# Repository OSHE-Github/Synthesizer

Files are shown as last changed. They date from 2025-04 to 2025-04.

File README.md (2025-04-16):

# Synthesizer

**Tips for uploading and running firmware on the Teensy**

- You will need the Arduino IDE to upload the firmware to the Teensy. Instructions: [Arduino IDE install instructions](https://support.arduino.cc/hc/en-us/articles/360019833020-Download-and-install-Arduino-IDE)
- Once Arduino IDE is installed, you will need the Teensyduino support package for Arduino IDE. Instructions: [Teensyduino install instructions](https://www.pjrc.com/teensy/td_download.html)
- You will also need to add the MIDI library into Arduino IDE. Instructions: [MIDI library instrall instructions](https://www.pjrc.com/teensy/td_libs_MIDI.html)
- The firmware should then be able to compile in Arduino IDE and upload to the Teensy by clicking the upload button. Make sure the Teensy is selected by going to Tools/Ports/ and select the correct serial port the Teensy is plugged into.

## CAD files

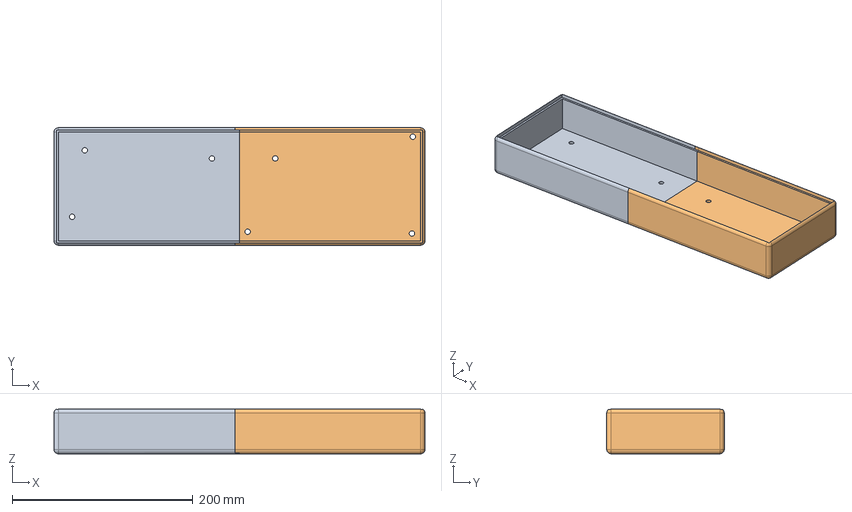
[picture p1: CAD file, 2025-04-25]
newcad/case-bottom-exploded.FCStd
410.0 x 130.0 x 49.3 mm
Slice.0
Slice.1

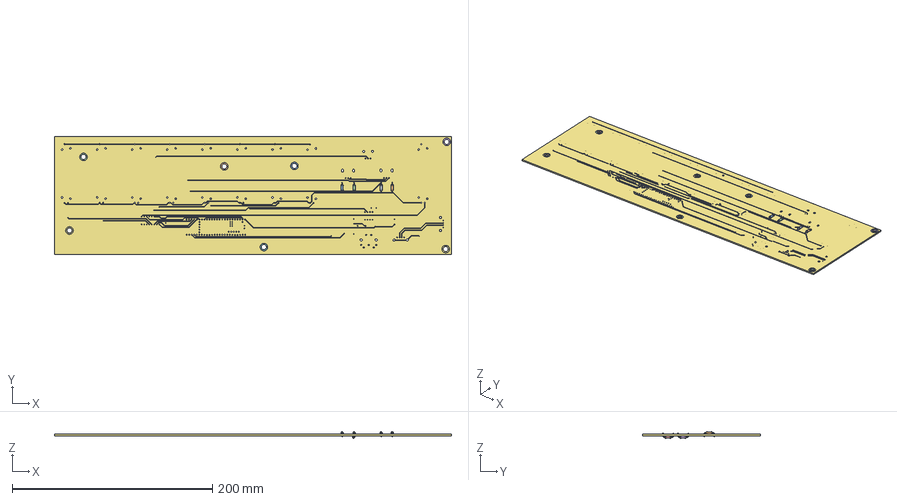
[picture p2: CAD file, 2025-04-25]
newcad/PCB.FCStd
396.2 x 117.5 x 6.66 mm
R_Axial_DIN0207_L6.3mm_D2.5mm_P10.16mm_Horizontal
R_Axial_DIN0207_L6.3mm_D2.5mm_P10.16mm_Horizontal001
R_Axial_DIN0207_L6.3mm_D2.5mm_P10.16mm_Horizontal002
R_Axial_DIN0207_L6.3mm_D2.5mm_P10.16mm_Horizontal003
R_Axial_DIN0207_L6.3mm_D2.5mm_P10.16mm_Horizontal004
R_Axial_DIN0207_L6.3mm_D2.5mm_P10.16mm_Horizontal005
Polysynth edit_copper
Polysynth edit_copper001
Polysynth edit_copper002
Polysynth edit_copper003
Polysynth edit_copper004
Polysynth edit_copper005
Polysynth edit_copper006
Polysynth edit_copper007
Polysynth edit_copper008
Polysynth edit_copper009
Polysynth edit_copper010
Polysynth edit_copper011
Polysynth edit_copper012
Polysynth edit_copper013
Polysynth edit_copper014
Polysynth edit_copper015
Polysynth edit_copper016
Polysynth edit_copper017
Polysynth edit_copper018
Polysynth edit_copper019
Polysynth edit_copper020
Polysynth edit_copper021
Polysynth edit_copper022
Polysynth edit_copper023
Polysynth edit_copper024
Polysynth edit_copper025
Polysynth edit_copper026
Polysynth edit_copper027
Polysynth edit_copper028
Polysynth edit_copper029
Polysynth edit_copper030
Polysynth edit_copper031
Polysynth edit_copper032
Polysynth edit_copper033
Polysynth edit_copper034
Polysynth edit_copper035
Polysynth edit_copper036
Polysynth edit_copper037
Polysynth edit_copper038
Polysynth edit_copper039
Polysynth edit_copper040
Polysynth edit_copper041
Polysynth edit_copper042
Polysynth edit_copper043
Polysynth edit_copper044
Polysynth edit_copper045
Polysynth edit_copper046
Polysynth edit_copper047
Polysynth edit_copper048
Polysynth edit_copper049
Polysynth edit_copper050
Polysynth edit_copper051
Polysynth edit_copper052
Polysynth edit_copper053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

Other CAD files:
newcad/case-bottom.FCStd

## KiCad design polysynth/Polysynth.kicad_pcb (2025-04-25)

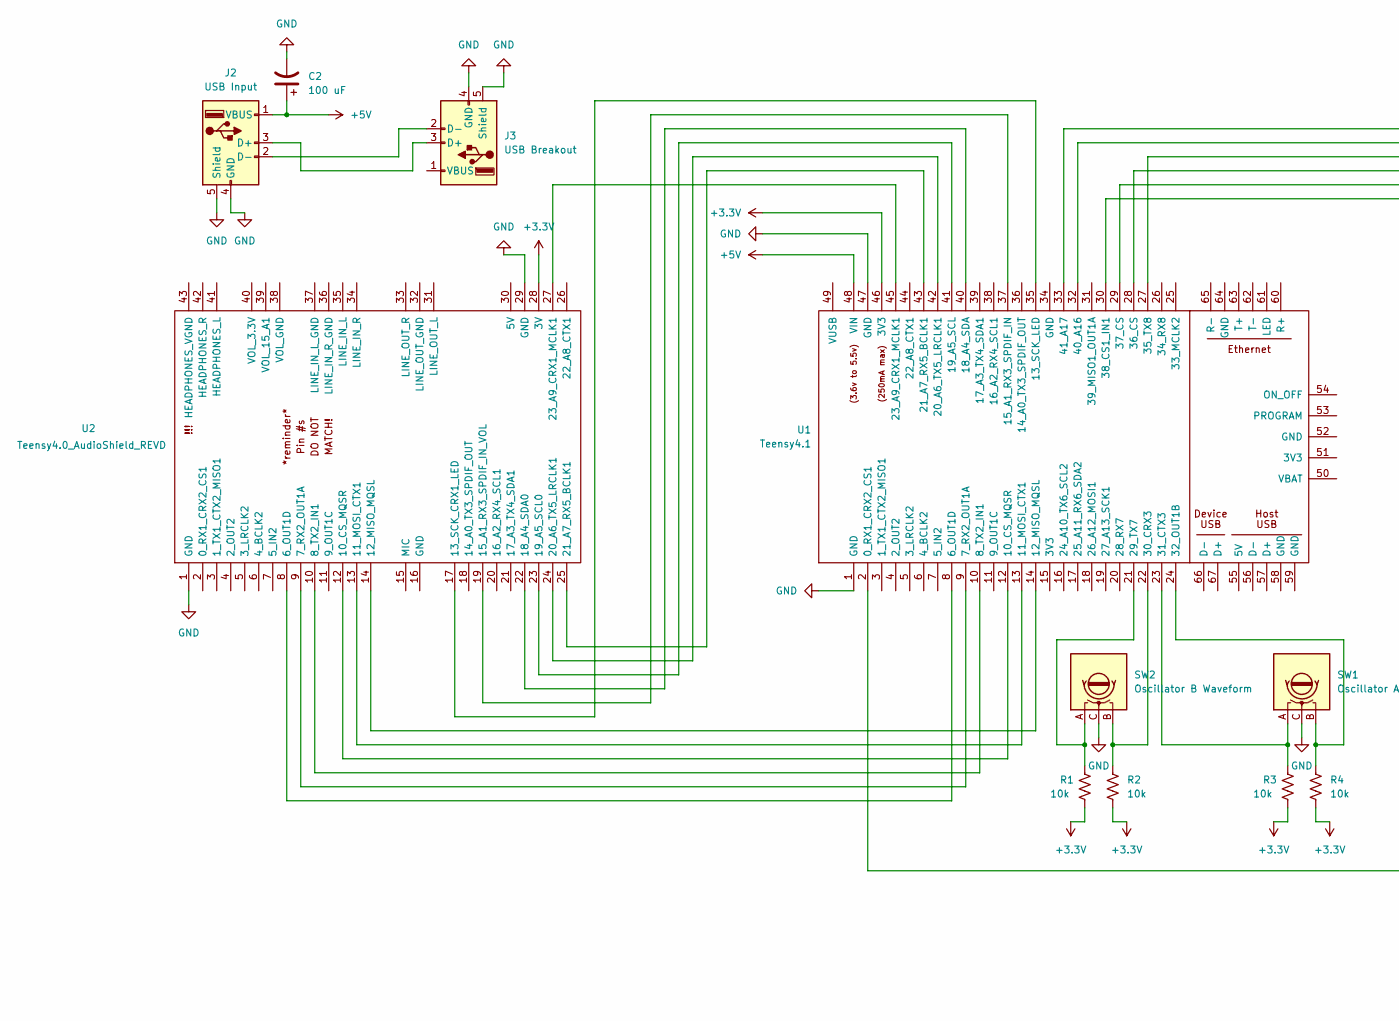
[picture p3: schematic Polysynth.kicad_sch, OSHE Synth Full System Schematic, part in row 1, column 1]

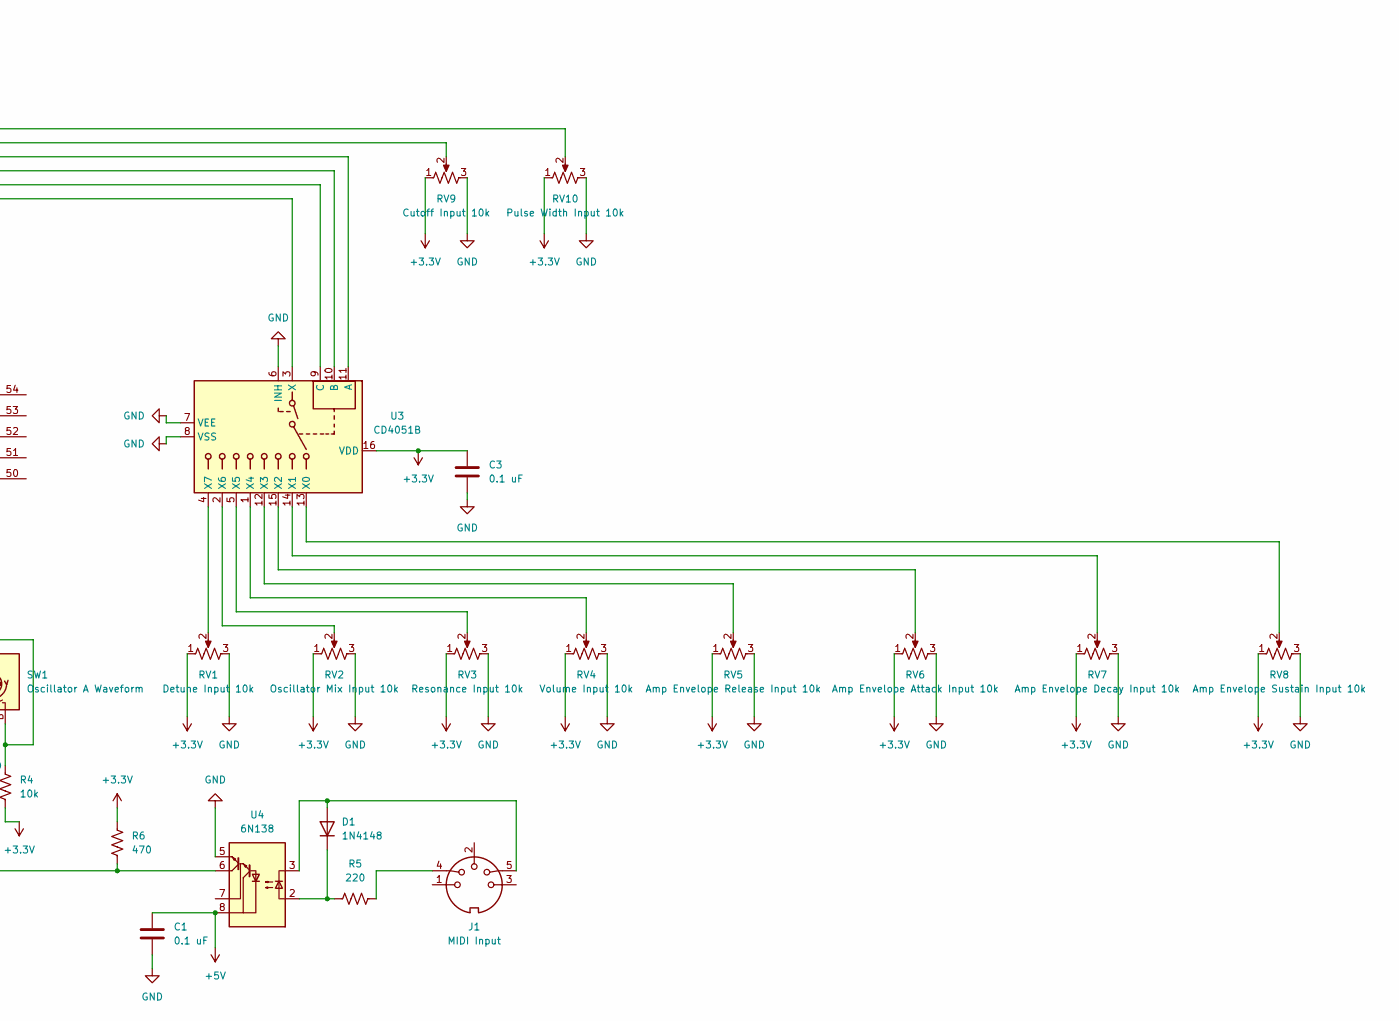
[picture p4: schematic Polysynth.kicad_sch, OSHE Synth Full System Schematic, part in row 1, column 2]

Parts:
C1, C3: 0.1 uF; radial_cap
C2: 100 uF; radial_cap_med
D1: 1N4148; DO-35_02_VIS
J1: MIDI Input; MIDI
J2: USB Input; USB_A_Stewart_SS-52100-001_Horizontal
J3: USB Breakout; USB_A_Stewart_SS-52100-001_Horizontal
R1, R2, R3, R4: 10k; R_Axial_DIN0207_L6.3mm_D2.5mm_P10.16mm_Horizontal
R5: 220; R_Axial_DIN0207_L6.3mm_D2.5mm_P10.16mm_Horizontal
R6: 470; R_Axial_DIN0207_L6.3mm_D2.5mm_P10.16mm_Horizontal
RV1: Detune Input 10k; Potentiometer_Bourns_PTA4543_Single_Slide
RV2: Oscillator Mix Input 10k; PDB12H4301103BF
RV3: Resonance Input 10k; Potentiometer_Bourns_PTA4543_Single_Slide
RV4: Volume Input 10k; Potentiometer_Bourns_PTA4543_Single_Slide
RV5: Amp Envelope Release Input 10k; Potentiometer_Bourns_PTA4543_Single_Slide
RV6: Amp Envelope Attack Input 10k; Potentiometer_Bourns_PTA4543_Single_Slide
RV7: Amp Envelope Decay Input 10k; Potentiometer_Bourns_PTA4543_Single_Slide
RV8: Amp Envelope Sustain Input 10k; Potentiometer_Bourns_PTA4543_Single_Slide
RV9: Cutoff Input 10k; Potentiometer_Bourns_PTA4543_Single_Slide
RV10: Pulse Width Input 10k; Potentiometer_Bourns_PTA4543_Single_Slide
SW1: Oscillator A Waveform; RotaryEncoder_Bourns_Vertical_PEC12R-3x17F-Nxxxx
SW2: Oscillator B Waveform; RotaryEncoder_Bourns_Vertical_PEC12R-3x17F-Nxxxx
U1: Teensy4.1; Teensy41
U2: Teensy4.0_AudioShield_REVD; 4.0audioshield
U3: CD4051B; CD4051BE
U4: 6N138

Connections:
+3.3V: C3.1, R1.2, R2.2, R3.2, R4.2, R6.1, RV1.1, RV2.1, RV3.1, RV4.1, RV5.1, RV6.1, RV7.1, RV8.1, RV9.1, RV10.1, U1.46 (3V3), U2.28 (3V), U3.16 (VDD)
+5V: C1.2, C2.1, J2.1 (VBUS), U1.48 (VIN), U4.8 (VCC)
GND: C1.1, C2.2, C3.2, J2.4 (GND), J2.5 (Shield), J3.4 (GND), J3.5 (Shield), RV1.3, RV2.3, RV3.3, RV4.3, RV5.3, RV6.3, RV7.3, RV8.3, RV9.3, RV10.3, SW1.C, SW2.C, U1.1 (GND), U1.47 (GND), U2.1 (GND), U2.29 (GND), U3.6 (INH), U3.7 (VEE), U3.8 (VSS), U4.5 (GND)
unnamed: D1.2 (A), J1.5, U4.3 (C2)
unnamed: D1.1 (K), R5.1, U4.2 (C1)
unnamed: J1.4, R5.2
unnamed: J2.3 (D+), J3.3 (D+)
unnamed: J2.2 (D-), J3.2 (D-)
unnamed: R6.2, U1.2 (0_RX1_CRX2_CS1), U4.6 (VO2)
unnamed: U1.8 (6_OUT1D), U2.8 (6_OUT1D)
unnamed: U1.9 (7_RX2_OUT1A), U2.9 (7_RX2_OUT1A)
unnamed: U1.10 (8_TX2_IN1), U2.10 (8_TX2_IN1)
unnamed: U1.12 (10_CS_MQSR), U2.12 (10_CS_MQSR)
unnamed: U1.13 (11_MOSI_CTX1), U2.13 (11_MOSI_CTX1)
unnamed: U1.14 (12_MISO_MQSL), U2.14 (12_MISO_MQSL)
unnamed: U1.35 (13_SCK_LED), U2.17 (13_SCK_CRX1_LED)
unnamed: U1.37 (15_A1_RX3_SPDIF_IN), U2.19 (15_A1_RX3_SPDIF_IN_VOL)
unnamed: U1.40 (18_A4_SDA), U2.22 (18_A4_SDA0)
unnamed: U1.41 (19_A5_SCL), U2.23 (19_A5_SCL0)
unnamed: U1.42 (20_A6_TX5_LRCLK1), U2.24 (20_A6_TX5_LRCLK1)
unnamed: U1.43 (21_A7_RX5_BCLK1), U2.25 (21_A7_RX5_BCLK1)
unnamed: U1.45 (23_A9_CRX1_MCLK1), U2.27 (23_A9_CRX1_MCLK1)
unnamed: R1.1, SW2.A, U1.21 (29_TX7)
unnamed: R2.1, SW2.B, U1.22 (30_CRX3)
unnamed: R3.1, SW1.A, U1.23 (31_CTX3)
unnamed: R4.1, SW1.B, U1.24 (32_OUT1B)
unnamed: U1.27 (35_TX8), U3.11 (A)
unnamed: U1.28 (36_CS), U3.10 (B)
unnamed: U1.29 (37_CS), U3.9 (C)
unnamed: U1.30 (38_CS1_IN1), U3.3 (X)
unnamed: RV9.2, U1.32 (40_A16)
unnamed: RV10.2, U1.33 (41_A17)
unnamed: RV8.2, U3.13 (X0)
unnamed: RV7.2, U3.14 (X1)
unnamed: RV6.2, U3.15 (X2)
unnamed: RV5.2, U3.12 (X3)
unnamed: RV4.2, U3.1 (X4)
unnamed: RV3.2, U3.5 (X5)
unnamed: RV2.2, U3.2 (X6)
unnamed: RV1.2, U3.4 (X7)

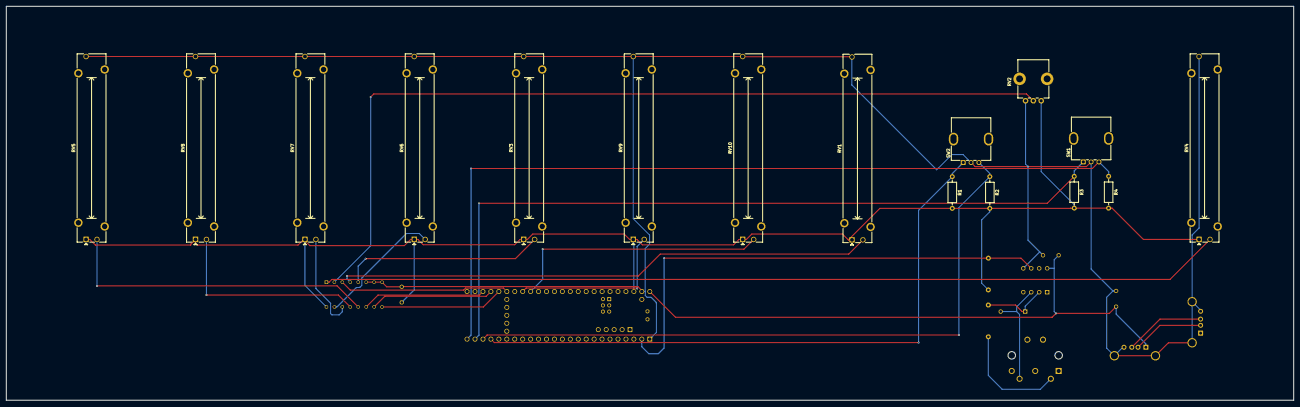
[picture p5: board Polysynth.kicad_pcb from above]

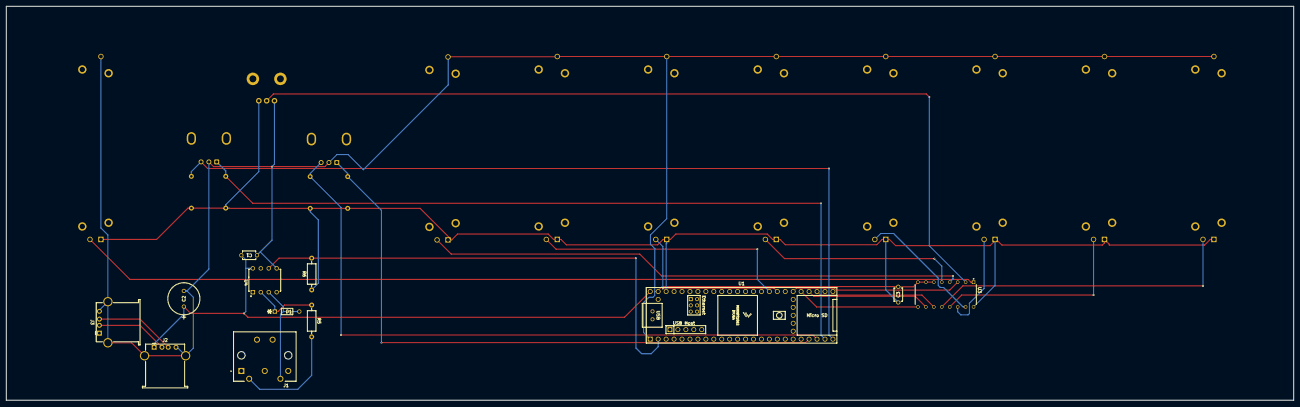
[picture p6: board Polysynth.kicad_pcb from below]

Board: 2 copper layers, 411.7 x 126.0 mm, 28 parts (12 on the bottom side), 27 nets.

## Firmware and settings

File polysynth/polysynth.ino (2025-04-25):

#include <MIDI.h>
#include <Audio.h>
#include <Wire.h>
#include <SPI.h>
#include <SD.h>
#include <SerialFlash.h>

MIDI_CREATE_INSTANCE(HardwareSerial, Serial1, MIDI); // create MIDI instance listening on Serial1 

const int voices = 8; // how many notes can be played at once
const int oscillators = 2; // how many oscillators (waveforms) per voice
const int waveforms = 5; // how many different waveshapes to choose from
const int waveform_switchA1 = 32; // pins of waveform selector switch for oscillators A and B
const int waveform_switchB1 = 30; 
const int waveform_switchA2 = 31;
const int waveform_switchB2 = 29;
const int led_pin = 31; // pin of indicator LED
const int mux1_s0 = 35; // pins used for mux select bits
const int mux1_s1 = 36;
const int mux1_s2 = 37;
const int mux1_inputs = 8; // how many inputs are used on mux 1

bool found_match = false; // utility variable used for searching arrays
byte midi_type = 0; // type of MIDI message being sent
int *midi_stack_ptr; // address of midi stack array
int default_waveform = 0;
int midi_note = 0; // which note was played
int midi_stack_index = 0; // current location in the MIDI stack
int notes_pressed_count = 0; // how many notes are currently held down
int notes_on_count = 0; // how many notes are currently sounding
int analog_res = 1024; // bit resolution used by ADCs
int detune_pot = 0; // _pot are values read from respective pots
int cutoff_pot = 0; 
int resonance_pot = 0; 
int amp_envelope_attack_pot = 0;
int amp_envelope_decay_pot = 0;
int amp_envelope_sustain_pot = 0;
int amp_envelope_release_pot = 0;
int pulse_width_pot = 0;
int volume_pot = 0;
int osc_mix_pot = 0;
int cutoff_range = 14950; // frequency range of filter (Hz)
int envelope_time_range = 11880; // time range of envelope parameters (ms)
int release_queue_count = 0; // amount of voices currently releasing
int waveform_switch_stateA = 0; // current status of the encoder (being turned or not)
int prev_waveform_switch_stateA = 1; // previous status of the encoder
int waveform_switch_stateB = 0;
int prev_waveform_switch_stateB = 1;
int new_voice = 0; // voice chosen to be used by allocation logic
float max_voice_gain = 0.12; // maximum allowed gain of a single voice (1/8 because 8 voices)
float filter_cutoff = 0; // current filter cutoff (Hz)
float filter_resonance = 0; // current filter resonance gain
float osc2_detune = 0; // current oscillator 2 detune (percent)
float pulse_width = 0; // current pulse width of pulse waveform (percent / 100)
float amp_envelope_decay = 0; // current amp envelope decay time (ms)
float amp_envelope_attack = 0; // current amp envelope attack time (ms)
float amp_envelope_release = 0; // currnet amp envelope release time (ms)
float pulse_width_range = 0.47; // range of pulse waveform pulse width (percent / 100)
float pulse_width_inc = 0; // _inc are scalar multipliers for interpreting pot values
float output_volume = 0; // gain of output volume (0-1)
float envelope_time_inc = 0;
float amp_sustain_level = 0; // envelope sustain level (0-1)
float cutoff_inc = 0;
float resonance_range = 4.3; // range of filter resonance (gain)
float resonance_inc = 0;
float frequency = 0; // frequency of note
float detune_range = 0.02973154717; // range of detuning oscillator 2 (percent - 1)
float detune_inc = 0;
float osc_mix_inc = 0;
float osc1_gain = 0; // gain level for oscillator 1
float osc2_gain = 0; //gain level for oscillator 2
bool voices_on[voices] = {false, false, false, false, false, false, false, false}; // which voices are currently being used by a held down note
bool notes_pressed[128]; // which notes are currently being pressed
bool notes_on[128]; // which notes are currently sounding
int mux_decode[8][3] = {{LOW, LOW, LOW}, {HIGH, LOW, LOW}, {LOW, HIGH, LOW}, {HIGH, HIGH, LOW}, {LOW, LOW, HIGH}, {HIGH, LOW, HIGH}, {LOW, HIGH, HIGH}, {HIGH, HIGH, HIGH}}; // maps mux input number to select signals
int midi_stack[128]; // LIFO of notes pressed
int voice_notes[voices] = {0, 0, 0, 0, 0, 0, 0, 0}; // which note is currently assigned to each voice
int release_queue[voices] = {0, 0, 0, 0, 0, 0, 0, 0}; // FIFO of voices still in release stage
int osc_waveforms[oscillators]; // which waveform is currently assigned to each oscillator
int waveform_lookup[waveforms] = {1, 2, 5, 3, 0}; // which waveforms are available (saw, square, pulse, triangle, sine)
float freq_table[128]; // lookup table for which frequency is for which MIDI note
float voice_freqs[voices]; // base note frequency currently assigned to each voice

AudioSynthWaveform osc1A; // creating all 16 oscillators (2 per voice)
AudioSynthWaveform osc1B;
AudioSynthWaveform osc2A;
AudioSynthWaveform osc2B;
AudioSynthWaveform osc3A;
AudioSynthWaveform osc3B;
AudioSynthWaveform osc4A;
AudioSynthWaveform osc4B;
AudioSynthWaveform osc5A;
AudioSynthWaveform osc5B;
AudioSynthWaveform osc6A;
AudioSynthWaveform osc6B;
AudioSynthWaveform osc7A;
AudioSynthWaveform osc7B;
AudioSynthWaveform osc8A;
AudioSynthWaveform osc8B;
AudioFilterStateVariable filter1; // creating all 8 filters
AudioFilterStateVariable filter2;
AudioFilterStateVariable filter3;
AudioFilterStateVariable filter4;
AudioFilterStateVariable filter5;
AudioFilterStateVariable filter6;
AudioFilterStateVariable filter7;
AudioFilterStateVariable filter8;
AudioEffectEnvelope amp_envelope1; // creating all 8 amplitude envelopes
AudioEffectEnvelope amp_envelope2;
AudioEffectEnvelope amp_envelope3;
AudioEffectEnvelope amp_envelope4;
AudioEffectEnvelope amp_envelope5;
AudioEffectEnvelope amp_envelope6;
AudioEffectEnvelope amp_envelope7;
AudioEffectEnvelope amp_envelope8;
AudioMixer4 voice1mix; // creating mixers used to create signal path
AudioMixer4 voice2mix;
AudioMixer4 voice3mix;
AudioMixer4 voice4mix;
AudioMixer4 voice5mix;
AudioMixer4 voice6mix;
AudioMixer4 voice7mix;
AudioMixer4 voice8mix;
AudioMixer4 voices1;
AudioMixer4 voices2;
AudioMixer4 voices3;
AudioOutputI2S i2s_out; // stereo output from audio shield DAC

AudioConnection patch1(osc1A, 0, voice1mix, 0); // connections to create signal path (Refer to DSP block diagram)
AudioConnection patch2(osc1B, 0, voice1mix, 1);
AudioConnection patch3(osc2A, 0, voice2mix, 0);
AudioConnection patch4(osc2B, 0, voice2mix, 1);
AudioConnection patch5(osc3A, 0, voice3mix, 0);
AudioConnection patch6(osc3B, 0, voice3mix, 1);
AudioConnection patch7(osc4A, 0, voice4mix, 0);
AudioConnection patch8(osc4B, 0, voice4mix, 1);
AudioConnection patch9(osc5A, 0, voice5mix, 0);
AudioConnection patch10(osc5B, 0, voice5mix, 1);
AudioConnection patch11(osc6A, 0, voice6mix, 0);
AudioConnection patch12(osc6B, 0, voice6mix, 1);
AudioConnection patch13(osc7A, 0, voice7mix, 0);
AudioConnection patch14(osc7B, 0, voice7mix, 1);
AudioConnection patch15(osc8A, 0, voice8mix, 0);
AudioConnection patch16(osc8B, 0, voice8mix, 1);
AudioConnection patch29(voice1mix, 0, filter1, 0);
AudioConnection patch30(voice2mix, 0, filter2, 0);
AudioConnection patch31(voice3mix, 0, filter3, 0);
AudioConnection patch32(voice4mix, 0, filter4, 0);
AudioConnection patch33(voice5mix, 0, filter5, 0);
AudioConnection patch34(voice6mix, 0, filter6, 0);
AudioConnection patch35(voice7mix, 0, filter7, 0);
AudioConnection patch36(voice8mix, 0, filter8, 0);
AudioConnection patch37(filter1, 0, amp_envelope1, 0);
AudioConnection patch38(filter2, 0, amp_envelope2, 0);
AudioConnection patch39(filter3, 0, amp_envelope3, 0);
AudioConnection patch40(filter4, 0, amp_envelope4, 0);
AudioConnection patch41(filter5, 0, amp_envelope5, 0);
AudioConnection patch42(filter6, 0, amp_envelope6, 0);
AudioConnection patch43(filter7, 0, amp_envelope7, 0);
AudioConnection patch44(filter8, 0, amp_envelope8, 0);
AudioConnection patch17(amp_envelope1, 0, voices1, 0);
AudioConnection patch18(amp_envelope2, 0, voices1, 1);
AudioConnection patch19(amp_envelope3, 0, voices1, 2);
AudioConnection patch20(amp_envelope4, 0, voices1, 3);
AudioConnection patch21(amp_envelope5, 0, voices2, 0);
AudioConnection patch22(amp_envelope6, 0, voices2, 1);
AudioConnection patch23(amp_envelope7, 0, voices2, 2);
AudioConnection patch24(amp_envelope8, 0, voices2, 3);
AudioConnection patch25(voices1, 0, voices3, 0);
AudioConnection patch26(voices2, 0, voices3, 1);
AudioConnection patch27(voices3, 0, i2s_out, 0);
AudioConnection patch28(voices3, 0, i2s_out, 1);

AudioControlSGTL5000 sgtl5000; // creating audio controller

void setup(){ // code that runs once at bootup
  MIDI.begin(MIDI_CHANNEL_OMNI); // start listening for MIDI messages
  Serial.begin(57600); // correct baud rate for MIDI I guess?
  AudioMemory(40); // allocate a bunch of memory for the audio library
  sgtl5000.enable(); // turn on audio controller
  sgtl5000.volume(0.51); // headphone volume
  voice1mix.gain(0, 0.06); // set all oscillators to initially have a gain of 1/16 (because 16 oscillators) to avoid distortion
  voice1mix.gain(1, 0.06);
  voice2mix.gain(0, 0.06);
  voice2mix.gain(1, 0.06);
  voice3mix.gain(0, 0.06);
  voice3mix.gain(1, 0.06);
  voice4mix.gain(0, 0.06);
  voice4mix.gain(1, 0.06);
  voice5mix.gain(0, 0.06);
  voice5mix.gain(1, 0.06);
  voice6mix.gain(0, 0.06);
  voice6mix.gain(1, 0.06);
  voice7mix.gain(0, 0.06);
  voice7mix.gain(1, 0.06);
  voice8mix.gain(0, 0.06);
  voice8mix.gain(1, 0.06); 
  voices1.gain(0, 1); // all following gains can stay at 1
  voices1.gain(1, 1);
  voices1.gain(2, 1);
  voices1.gain(3, 1);
  voices2.gain(0, 1);
  voices2.gain(1, 1);
  voices2.gain(2, 1);
  voices2.gain(3, 1);
  voices3.gain(0, 1);
  voices3.gain(1, 1);
  filter1.octaveControl(1);
  filter2.octaveControl(1);
  filter3.octaveControl(1);
  filter4.octaveControl(1);
  filter5.octaveControl(1);
  filter6.octaveControl(1);
  filter7.octaveControl(1);
  filter8.octaveControl(1);
  pinMode(32, INPUT); // waveform select pins should be inputs
  pinMode(31, INPUT); 
  pinMode(30, INPUT);
  pinMode(29, INPUT);
  pinMode(35, OUTPUT); //  mux select pins should be output
  pinMode(36, OUTPUT);
  pinMode(37, OUTPUT);
  midi_stack_ptr = &midi_stack[0]; // address of MIDI stack
  detune_inc = detune_range / analog_res; // calculate increase percentage per increment of pot value
  cutoff_inc = cutoff_range / analog_res; // calculate increase of cutoff frequency (Hz) per increment of pot value
  resonance_inc = resonance_range / analog_res; // calculate increase of resonange gain per increment of pot value
  envelope_time_inc = envelope_time_range / analog_res; // calculate increase of envelope time (ms) per increment of pot value
  pulse_width_inc = pulse_width_range / analog_res; // calculate increase of pulse width (percent / 100) per increment of pot value
  osc_mix_inc = max_voice_gain / analog_res; // calculate increase of oscillator gain per increment of pot value
  create_freq_table(); // fill frequency table that associates each MIDI note with its frequency
  osc1A.begin(waveform_lookup[default_waveform]); // each oscillator should first boot up with whatever the default waveform is set to
  osc1B.begin(waveform_lookup[default_waveform]);
  osc2A.begin(waveform_lookup[default_waveform]);
  osc2B.begin(waveform_lookup[default_waveform]);
  osc3A.begin(waveform_lookup[default_waveform]);
  osc3B.begin(waveform_lookup[default_waveform]);
  osc4A.begin(waveform_lookup[default_waveform]);
  osc4B.begin(waveform_lookup[default_waveform]);
  osc5A.begin(waveform_lookup[default_waveform]);
  osc5B.begin(waveform_lookup[default_waveform]);
  osc6A.begin(waveform_lookup[default_waveform]);
  osc6B.begin(waveform_lookup[default_waveform]);
  osc7A.begin(waveform_lookup[default_waveform]);
  osc7B.begin(waveform_lookup[default_waveform]);
  osc8A.begin(waveform_lookup[default_waveform]);
  osc8B.begin(waveform_lookup[default_waveform]);
}

void create_freq_table(){ // fills frequency table that associates each MIDI note with its frequency
  for(int i = 0; i < 128; i++){
    float curr_freq = i - 69; // equation for converting MIDI note to note frequency
    curr_freq = curr_freq / 12;
    curr_freq = pow(2, curr_freq);
    curr_freq = 440 * curr_freq;
    freq_table[i] = curr_freq;
  }
}

bool check_amp_envelope(int voice){ // checks the amp envelope of a given voice to see if it is currently still in any stage of ADSR
  switch(voice){
    case 0:
      if(amp_envelope1.isActive()){
        return true;
      }else{
        return false;
      }
      break;
    case 1:
      if(amp_envelope2.isActive()){
        return true;
      }else{
        return false;
      }
      break;
    case 2:
      if(amp_envelope3.isActive()){
        return true;
      }else{
        return false;
      }
      break;
    case 3:
      if(amp_envelope4.isActive()){
        return true;
      }else{
        return false;
      }
      break;
    case 4:
      if(amp_envelope5.isActive()){
        return true;
      }else{
        return false;
      }
      break;
    case 5:
      if(amp_envelope6.isActive()){
        return true;
      }else{
        return false;
      }
      break;
    case 6:
      if(amp_envelope7.isActive()){
        return true;
      }else{
        return false;
      }
      break;
    case 7:
      if(amp_envelope8.isActive()){
        return true;
      }else{
        return false;
      }
      break;
    default:
      return false;
  }
}

void update_amp_envelope(int voice, bool start){ // begins (starts attack phase) or ends (begins release phase) the amp envelope of a given voice
  switch(voice){
    case 0:
      if(start){ // if envelope should be starting
        amp_envelope1.noteOn();
        osc1A.amplitude(0.3); // kind of arbitrary maximum oscillator amplitude
        osc1B.amplitude(0.3);
      }else{ // if envelope should be ending
        amp_envelope1.noteOff();
      }
      break;
    case 1:
      if(start){
        amp_envelope2.noteOn();
        osc2A.amplitude(0.3);
        osc2B.amplitude(0.3);
      }else{
        amp_envelope2.noteOff();
      }
      break;
    case 2:
      if(start){
        amp_envelope3.noteOn();
        osc3A.amplitude(0.3);
        osc3B.amplitude(0.3);
      }else{
        amp_envelope3.noteOff();
      }
      break;
    case 3:
      if(start){
        amp_envelope4.noteOn();
        osc4A.amplitude(0.3);
        osc4B.amplitude(0.3);
      }else{
        amp_envelope4.noteOff();
      }
      break;
    case 4:
      if(start){
        amp_envelope5.noteOn();
        osc5A.amplitude(0.3);
        osc5B.amplitude(0.3);
      }else{
        amp_envelope5.noteOff();
      }
      break;
    case 5:
      if(start){
        amp_envelope6.noteOn();
        osc6A.amplitude(0.3);
        osc6B.amplitude(0.3);
      }else{
        amp_envelope6.noteOff();
      }
      break;
    case 6:
      if(start){
        amp_envelope7.noteOn();
        osc7A.amplitude(0.3);
        osc7B.amplitude(0.3);
      }else{
        amp_envelope7.noteOff();
      }
      break;
    case 7:
      if(start){
        amp_envelope8.noteOn();
        osc8A.amplitude(0.3);
        osc8B.amplitude(0.3);
      }else{
        amp_envelope8.noteOff();
      }
      break;
  }
}

void update_note(int voice){ // changes the note (frequency) that the oscillators of a given voice are playing
  switch(voice){
    case 0:
      osc1A.frequency(voice_freqs[0]);
      osc1B.frequency(voice_freqs[0] * ((detune_pot * detune_inc) + 1)); // oscillator 2 can be detuned from oscillator 1
      break;
    case 1:
      osc2A.frequency(voice_freqs[1]);
      osc2B.frequency(voice_freqs[1] * ((detune_pot * detune_inc) + 1));
      break;
    case 2:
      osc3A.frequency(voice_freqs[2]);
      osc3B.frequency(voice_freqs[2] * ((detune_pot * detune_inc) + 1));
      break;
    case 3:
      osc4A.frequency(voice_freqs[3]);
      osc4B.frequency(voice_freqs[3] * ((detune_pot * detune_inc) + 1));
      break;
    case 4:
      osc5A.frequency(voice_freqs[4]);
      osc5B.frequency(voice_freqs[4] * ((detune_pot * detune_inc) + 1));
      break;
    case 5:
      osc6A.frequency(voice_freqs[5]);
      osc6B.frequency(voice_freqs[5] * ((detune_pot * detune_inc) + 1));
      break;
    case 6:
      osc7A.frequency(voice_freqs[6]);
      osc7B.frequency(voice_freqs[6] * ((detune_pot * detune_inc) + 1));
      break;
    case 7:
      osc8A.frequency(voice_freqs[7]);
      osc8B.frequency(voice_freqs[7] * ((detune_pot * detune_inc) + 1));
      break;
  }
}
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
